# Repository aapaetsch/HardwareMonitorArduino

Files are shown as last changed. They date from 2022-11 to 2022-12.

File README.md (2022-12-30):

## Rough Overview of the project so far:
- Desktop Hardware Monitor: Contains the PCB Files for the project.
- Hardware_Monitor: Contains the arduino code for an arduino microcontroller, currently this is an ATMEGA328p-pu. 
  - This will be used to drive 6x7 segment displays (common cathode) and (hopefully) 2 i2c 128X64px screens.
  - Drivers for the I2C displays still need to be coded.
  - Some logic from the output pins will need to be offloaded to external IC chips
    - So far 74HC164 8-bit Shift Register, 74LS04 hex inverter, 74LS138 
  - Serial inverters are bulky, maybe V-USB if the chip has enough storage after the program is close to finished in size...
- HardwareMonitorArduino: Contains the code related to a C# program that will run on the host pc. (Incomplete) Will share code with my DesktopHardwareMonitor electron application.

V1 PCB - No Input USB and requires a redesign as it does not fit in the 100mm x 100mm limit for JLPCB 







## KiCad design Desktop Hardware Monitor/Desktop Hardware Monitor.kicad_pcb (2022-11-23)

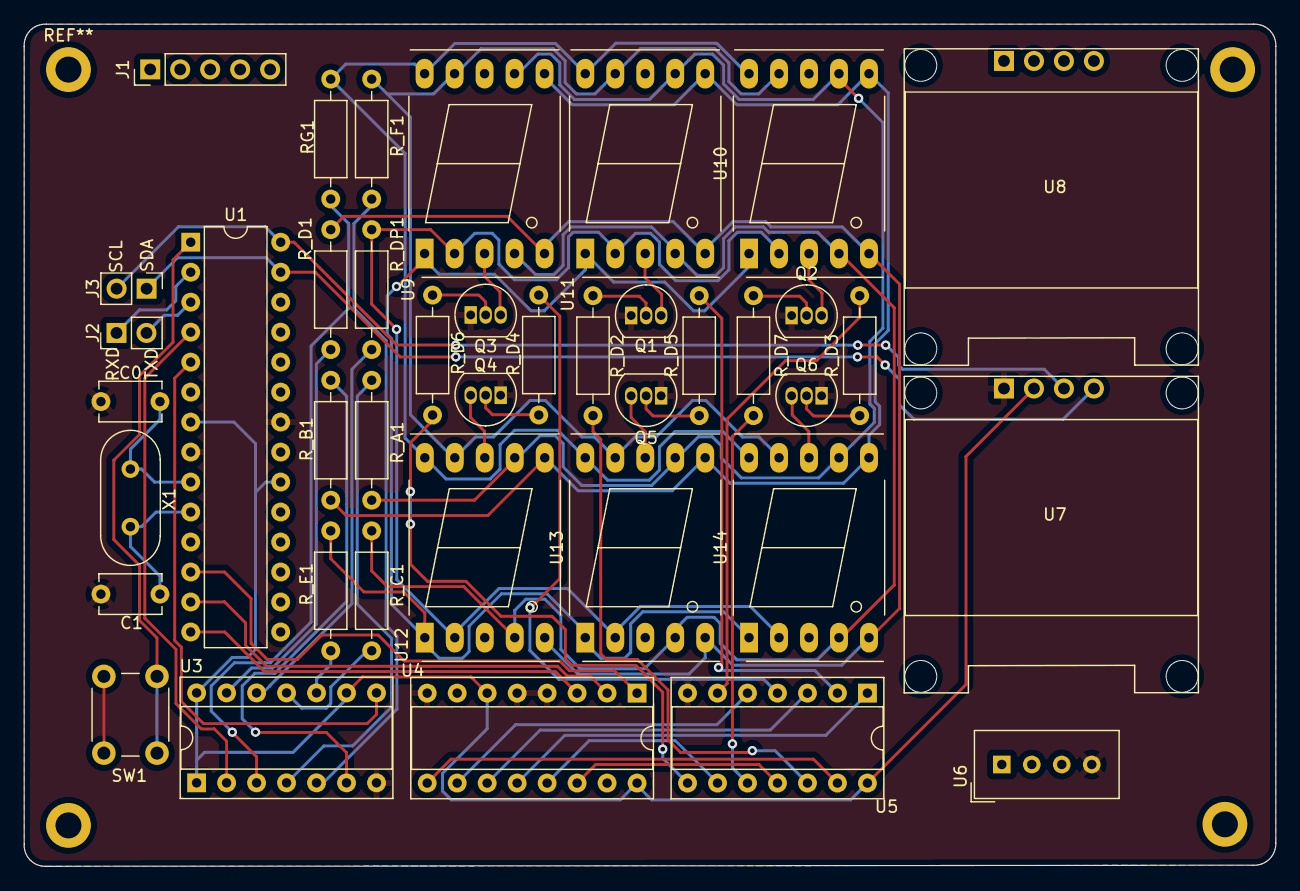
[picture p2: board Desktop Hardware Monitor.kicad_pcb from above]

Board: 2 copper layers, 106.0 x 71.3 mm, 40 parts (0 on the bottom side), 54 nets.

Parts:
C0, C1: 22pf; C_Disc_D5.1mm_W3.2mm_P5.00mm
J1: USB_C_Receptacle_USB2.0; PinHeader_1x05_P2.54mm_Vertical
J2, J3: Conn_01x02_Female; PinHeader_1x02_P2.54mm_Vertical
Q1, Q2, Q3, Q4, Q5, Q6: 2N3904; TO-92_Inline
RG1: 1K; R_Axial_DIN0207_L6.3mm_D2.5mm_P10.16mm_Horizontal
R_A1: 1K; R_Axial_DIN0207_L6.3mm_D2.5mm_P10.16mm_Horizontal
R_B1: 1K; R_Axial_DIN0207_L6.3mm_D2.5mm_P10.16mm_Horizontal
R_C1: 1K; R_Axial_DIN0207_L6.3mm_D2.5mm_P10.16mm_Horizontal
R_D1, R_D2, R_D3, R_D4, R_D5, R_D6, R_D7: 1K; R_Axial_DIN0207_L6.3mm_D2.5mm_P10.16mm_Horizontal
R_DP1: 1K; R_Axial_DIN0207_L6.3mm_D2.5mm_P10.16mm_Horizontal
R_E1: 1K; R_Axial_DIN0207_L6.3mm_D2.5mm_P10.16mm_Horizontal
R_F1: 1K; R_Axial_DIN0207_L6.3mm_D2.5mm_P10.16mm_Horizontal
SW1: Reset Switch; SW_PUSH_6mm_H4.3mm
U1: ATmega328-P; DIP-28_W7.62mm
U3: 74HC164; DIP-14_W7.62mm_Socket
U4: 74LS138; DIP-16_W7.62mm_Socket
U5: 74LS04; DIP-14_W7.62mm_Socket
U6: DHT11; Aosong_DHT11_5.5x12.0_P2.54mm
U7, U8: SSD1306; IC2_Display_4_Pin
U9, U10, U11, U12, U13, U14: SM420561N; 7SegmentLED_LTS6760_LTS6780
X1: XTAL; Crystal_HC49-4H_Vertical

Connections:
A: R_A1.1, U3.4 (Q1)
A0: U1.12 (PD6), U4.1 (A0)
A1: U1.13 (PD7), U4.2 (A1)
A2: U1.14 (PB0), U4.3 (A2)
B: R_B1.1, U3.6 (Q3)
C: R_C1.1, U3.11 (Q5)
CLK: U1.5 (PD3), U3.8 (CLK)
D: R_D1.1, U3.12 (Q6)
DP: R_DP1.1, U3.13 (Q7)
DSB: U1.4 (PD2), U3.2 (DSB)
Digit1: Q1.3 (C), U11.3 (CC)
Digit2: Q2.3 (C), U10.3 (CC)
Digit3: Q3.3 (C), U9.3 (CC)
Digit4: Q4.3 (C), U12.8 (CC)
Digit5: Q5.3 (C), U13.8 (CC)
Digit6: Q6.3 (C), U14.8 (CC)
E: R_E1.1, U3.10 (Q4)
F: R_F1.1, U3.5 (Q2)
G: RG1.1, U3.3 (Q0)
GND: C0.2, C1.2, Q1.1 (E), Q2.1 (E), Q3.1 (E), Q4.1 (E), Q5.1 (E), Q6.1 (E), SW1.2, U1.8 (GND), U1.22 (GND), U3.7 (GND), U4.4 (E1), U4.5 (E2), U4.8 (GND), U5.7 (GND), U6.4 (GND), U7.1 (C2P)
unnamed: Q1.2 (B), R_D2.1
unnamed: Q2.2 (B), R_D7.1
unnamed: Q3.2 (B), R_D6.1
unnamed: Q4.2 (B), R_D4.1
unnamed: Q5.2 (B), R_D5.1
unnamed: Q6.2 (B), R_D3.1
unnamed: RG1.2, U9.10 (G), U10.10 (G), U11.10 (G), U12.10 (G), U13.10 (G), U14.10 (G)
unnamed: R_A1.2, U9.7 (A), U10.7 (A), U11.7 (A), U12.7 (A), U13.7 (A), U14.7 (A)
unnamed: R_B1.2, U9.6 (B), U10.6 (B), U11.6 (B), U12.6 (B), U13.6 (B), U14.6 (B)
unnamed: R_C1.2, U9.4 (C), U10.4 (C), U11.4 (C), U12.4 (C), U13.4 (C), U14.4 (C)
unnamed: R_D1.2, U9.2 (D), U10.2 (D), U11.2 (D), U12.2 (D), U13.2 (D), U14.2 (D)
unnamed: R_D2.2, U5.12
unnamed: R_D3.2, U5.6
unnamed: R_D4.2, U5.4
unnamed: R_D5.2, U5.2
unnamed: R_D6.2, U5.8
unnamed: R_D7.2, U5.10
unnamed: R_DP1.2, U9.5 (DP), U10.5 (DP), U11.5 (DP), U12.5 (DP), U13.5 (DP), U14.5 (DP)
unnamed: R_E1.2, U9.1 (E), U10.1 (E), U11.1 (E), U12.1 (E), U13.1 (E), U14.1 (E)
unnamed: R_F1.2, U9.9 (F), U10.9 (F), U11.9 (F), U12.9 (F), U13.9 (F), U14.9 (F)
unnamed: U4.9 (O6), U5.13
unnamed: U4.10 (O5), U5.5
unnamed: U4.11 (O4), U5.3
unnamed: U4.12 (O3), U5.1
unnamed: U4.13 (O2), U5.9
unnamed: U4.14 (O1), U5.11
RST: SW1.1, U1.1 (~RESET/PC6)
RXD: J2.1, U1.2 (PD0)
SCL: J3.2, U1.28 (PC5), U7.3 (C1P)
SDA: J3.1, U1.27 (PC4), U7.4 (C1N)
TXD: J2.2, U1.3 (PD1)
VCC: U1.7 (VCC), U1.20 (AVCC), U3.1 (DSA), U3.9 (~CLR), U3.14 (VCC), U4.6 (E3), U4.16 (VCC), U5.14 (VCC), U6.1 (VCC), U7.2 (C2N)
XTAL1: C0.1, U1.9 (XTAL1/PB6), X1.1
XTAL2: C1.1, U1.10 (XTAL2/PB7), X1.2

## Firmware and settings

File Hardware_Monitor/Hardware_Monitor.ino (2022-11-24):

#include "SoftwareI2C.h"
#include <Wire.h>
#include <Adafruit_GFX.h>
#include <Adafruit_SSD1306.h>
#include <string.h>
#include "7SegmentArrayDriver.h"

#define data 12
#define clock 11
#define drainA 6
#define drainB 7
#define drainC 8

#define digitalSck 16
#define digitalSda 15

#define SCREEN_WIDTH 128
#define SCREEN_HEIGHT 64

byte A = B11101110;
byte b = B11110000;
byte C = B01111000;
byte c = B10011000;
byte d = B10111100;
byte E = B11111000;
byte e = B11110110;
byte F = B11100010;
byte G = B01111100;
byte p = B11101010;
byte u = B00111110;

Adafruit_SSD1306 display(SCREEN_WIDTH, SCREEN_HEIGHT, &Wire, -1);
SevenSegmentArrayDriver displayDriver(drainA, drainB, drainC, data, clock);

// #region I2C Bus
// #endregion I2C Bus

void setup()
{
  pinMode(clock, OUTPUT); // make the clock pin an output
  pinMode(data , OUTPUT); // make the data pin an output3
  pinMode(drainA, OUTPUT);
  pinMode(drainB, OUTPUT);
  pinMode(drainC, OUTPUT);
  Serial.begin(9600);
  Wire.begin();
  if (!display.begin(SSD1306_SWITCHCAPVCC, 0x3C)) {
    Serial.println(F("SSD1306 allocation failed Port"));
    for(;;);
  }
  display.clearDisplay();
  
}
//void renderDisplayGroup(byte pattern1, byte pattern2, byte pattern3, int delayTime, bool isFirst = true) {
//  if (isFirst) {
//    renderDigit(0, pattern1, delayTime);
//    renderDigit(1, pattern2, delayTime);
//    renderDigit(2, pattern3, delayTime);
//  } else {
//    renderDigit(3, pattern1, delayTime);
//    renderDigit(4, pattern2, delayTime);
//    renderDigit(5, pattern3, delayTime);
//  }
//}
int count = 0;
String inData;

void loop()
{
      displayDriver.renderDisplayGroup(G,p,u,3, true);
      displayDriver.renderDisplayGroup(C,p,u,3, false);
      if (count % 100 == 0) {
        display.setTextSize(0.5);
        display.setTextColor(WHITE);
//        display.clearDisplay();
//        display.setCursor(0, 0);
//        display.println(F("This GPU Be Sweatting"));
//        display.display();
      }
//      if (count %505 == 0) {
//        
//        while (Serial.available() > 0)
//        {
//            char recieved = Serial.read();
//            inData += recieved; 
//            renderDisplayGroup(C,p,u,3, false);
//            if (recieved == '*')
//            {
//              
//                inData.remove(inData.length() - 1, 1);
//                display.setCursor(0,0);
//                display.clearDisplay();
//                display.println("GPU Temp.: " + inData + char(223)+"C ");
//                inData = ""; 
//                
//                if(inData == "DIS")
//                {   
//                  display.clearDisplay();
//                  display.setCursor(0,0);
//                  display.print("Disconnected!");
//                }
//            } 
//            
//            if (recieved == '#')
//            {
//                inData.remove(inData.length() - 1, 1);
//                display.setCursor(0,10);
//                display.clearDisplay();
//                display.print("CPU Temp.: " + inData + char(223)+"C ");
//                inData = ""; 
//            }
//            display.display();
//            renderDisplayGroup(G,p,u,3);
//            renderDisplayGroup(C,p,u,3, false);
//        }
//        count = 0;
//      }
     
    count = count + 1;
}
      

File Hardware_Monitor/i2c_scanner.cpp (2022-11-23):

#include "i2c_scanner.h"
#include <Wire.h>

I2C_Scanner::I2C_Scanner(int baudRate, int delayTime) {
  if (baudRate == -1) 
  {
    baud = 19200;
  } 
  else 
  {
    baud = baudRate;  
  }
  if (delayTime == -1) 
  {
    scanDelay = 5000;  
  }
  else
  {
    scanDelay = delayTime;
  }
}

void I2C_Scanner::setupWire() {
  Wire.begin();
  Serial.begin(baud);
  while(!Serial);
  Serial.println("\nI2C Scanner");
}

void I2C_Scanner::onLoop() {
  byte error, address;
  int nDevices;
  Serial.println("Scanning...");
  nDevices = 0;
  for(address = 1; address < 127; address++ ) 
  {
    // The i2c_scanner uses the return value of
    // the Write.endTransmisstion to see if
    // a device did acknowledge to the address.
    Wire.beginTransmission(address);
    error = Wire.endTransmission();
    if (error == 0)
    {
      Serial.print("I2C device found at address 0x");
      if (address<16) 
      {
        Serial.print("0");
      }  
      Serial.print(address,HEX);
      Serial.println("  !");
      nDevices++;
    }
    else if (error==4) 
    {
      Serial.print("Unknown error at address 0x");
      if (address<16) 
      {
        Serial.print("0");
      }
      Serial.println(address,HEX);
    }    
  }
  if (nDevices == 0){
    Serial.println("No I2C devices found\n");
  }
    
  else {
    Serial.println("done\n");
  }
  delay(scanDelay);
}

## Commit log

2022-11-19 Initial commit, this contains the start of the code for driving the arduino and the rough windows app to get hardware data from the pc
2022-11-19 Commit kicad files
    [Desktop Hardware Monitor V1.kicad_sch, Desktop Hardware Monitor.kicad_pcb, Desktop Hardware Monitor.kicad_sch]
2022-11-23 Add start of arduino side of project
2022-11-23 Start switch to using LibreHardwareMonitor instead of open hardware monitor
    - OpenHardwareMonitor was missing the vast majority of sensors, only working on the gpu and partially on the cpu
2022-11-23 Update PCB Files
    [Desktop Hardware Monitor.kicad_pcb, Desktop Hardware Monitor.kicad_sch]
2022-11-24 Update 7 segment driver code to use a separate class
